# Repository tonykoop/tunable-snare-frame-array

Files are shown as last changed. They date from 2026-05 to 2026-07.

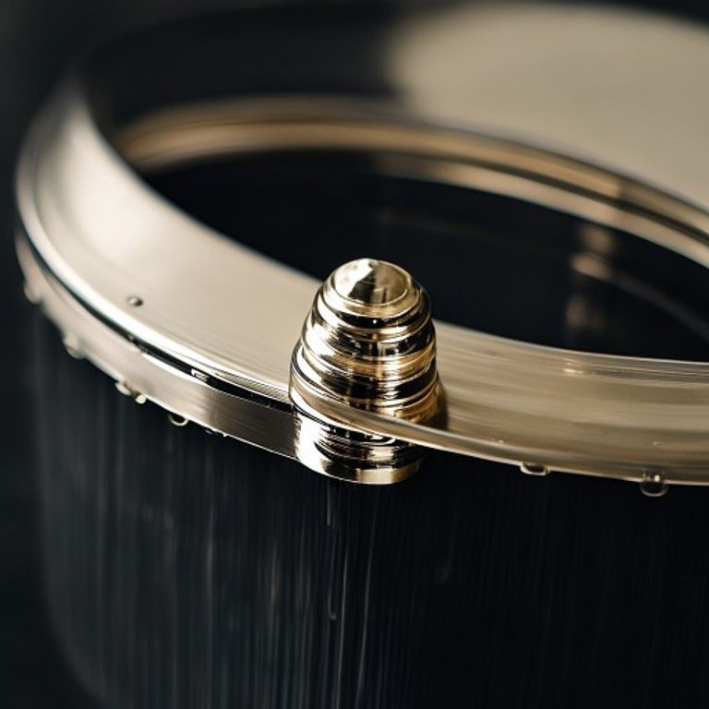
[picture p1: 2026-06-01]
images/macro/tension-snare-hardware.png

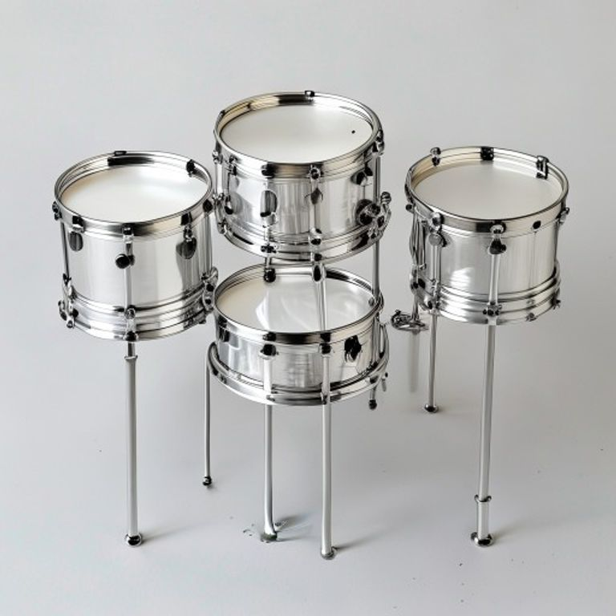
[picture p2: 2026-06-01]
images/hero-render.png

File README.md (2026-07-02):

<!-- SPDX-License-Identifier: CC-BY-4.0 -->
# Tunable Snare Frame Array

**Family:** Percussion · Membranophone · Frame drum  
**Target tuning:** D3 / A3 / D4 (3-pitch D minor triad cluster, ±50 cents, tunable by head tension)  
**Ergonomic envelope:** Three frame drums (150 mm, 200 mm, 250 mm OD) mounted side-by-side on a 450 mm shared steel bracket frame; total playing width ≈ 550 mm, height ≈ 300 mm, depth ≈ 80 mm  
**Status:** L2 V5 build-packet candidate

---

## Design Thesis

Three small snare-style frame drums of graduated diameter share a single plasma-cut cold-rolled steel mounting bracket. Each drum is independently tensioned via standard drum lug hardware, allowing the player to dial in a chromatic or open-tuned 3-pitch array. Bought drum heads (Remo Ambassador, 6″/8″/10″) and bought snare wires (8–12 strand) keep the build approachable; the sheet-metal work is three rolled cylinders and one flat mounting bracket — well within Maker Nexus slip-roll + plasma workflow.

The instrument reads as a hand-percussion kit (clave-like cross-stick, brushed rim shots, snare rattles on all three pitches) with enough pitch separation to imply melody. It is a greenfield v0.1.0-blueprint — all dimensions and acoustic targets are derived estimates pending a first prototype.

---

## Quick Start

| File | Purpose |
|---|---|
| `design.md` | Parametric design + acoustic model |
| `parameters.csv` | All dimensions — single source of truth |
| `tunable-snare-frame-array-starter.wl` | First-order membrane frequency model |
| `validation.csv` | Predicted targets + measurement gates |
| `fabrication-plan.md` | Maker Nexus cut → roll → weld → assemble sequence |
| `bom.csv` | Bill of materials with supplier hints |
| `explorer.html` | Single-page packet viewer |
| `cad/tunable-snare-frame-array.scad` | Parametric OpenSCAD shell + frame envelope master (`pending_measurement`) |
| `evolution/` | evolution-pipeline Stage 0 intake: master manifest, design-intent, revision register (Gate A not yet run) |

---

## License

Hardware: CERN-OHL-W v2.0 · Docs: CC BY 4.0 — see `LICENSE`.

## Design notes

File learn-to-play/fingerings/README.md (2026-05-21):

<!-- SPDX-License-Identifier: CC-BY-4.0 -->
# Fingerings — Tunable Snare Frame Array

> **Stub** — diagrams pending prototype build.

## Drum layout (from player's perspective)

```
  ┌─────────────────────────────────────────┐
  │    [Drum A]     [Drum B]     [Drum C]   │
  │    D3 10"       A3 8"        D4 6"      │
  │                                         │
  │  ← left hand    right hand →            │
  └─────────────────────────────────────────┘
                 (player)
```

## Hand assignment suggestions

| Preference | Left hand | Right hand |
|---|---|---|
| Default | Drum A (D3) + Drum C (D4 reach) | Drum B (A3) primary |
| Bass-lead | Drum A (D3) primary | Drum B + Drum C |
| Equal | Alternate A↔C with left, B primary right | — |

## Strike zones (per drum, plan view)

```
       ┌─────────────────┐
       │    ● center     │  ← fundamental pitch, max resonance
       │  ●   ●  mid     │  ← cleaner, less overtone
       │ ●       ● edge  │  ← bright, short decay
       └─────────────────┘
```

Add diagrams here once instrument is built (PH-11 playing-position photo from photo-shotlist.md).

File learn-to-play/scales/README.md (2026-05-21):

<!-- SPDX-License-Identifier: CC-BY-4.0 -->
# Scales & Patterns — Tunable Snare Frame Array

> **Stub** — patterns pending prototype build.

## Available pitch set

```
D3 (Drum A) — A3 (Drum B) — D4 (Drum C)
```

This is a power-chord voicing (D–A–D): root → fifth → octave.
It fits rock/metal feels, modal drones, and ostinato percussion lines.

## Basic pulse patterns ★☆☆

**Single-drum quarter pulse** — pick one drum, tap center on every beat:
```
Beat:  1  2  3  4
Drum:  A  A  A  A
```

**Three-drum rotation** — cycle through all three:
```
Beat:  1  2  3
Drum:  A  B  C  A  B  C ...
```

## Two-drum cross ★★☆

**Bass + treble split** — A on beats 1 & 3, C on 2 & 4, B fills:
```
Beat:  1  +  2  +  3  +  4  +
Drum:  A     C     A     C
           B           B
```

## Snare interplay ★★☆

Enable snare on Drum B only. Play the three-drum rotation above —
Drum B will have snare texture while A and C are clean membrane.
Gradually engage snare on A or C for increasing density.

## Three-drum polyrhythm ★★★

**3 against 2 (hemiola)** — Drum A in 3, Drums B+C in 2:
```
Beat grid (6 units):
A:  ●  .  .  ●  .  .   (every 3)
B:  ●  .  .  ●  .  .
C:  ●  .  .  .  ●  .   (every 2, offset)
```

Expand this file with tablature notation once prototype testing
confirms target pitches (VAL-009 through VAL-011 in validation.csv).

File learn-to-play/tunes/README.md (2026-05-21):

<!-- SPDX-License-Identifier: CC-BY-4.0 -->
# Tunes — Tunable Snare Frame Array

> **Stub** — arrangements pending prototype build.

## Planned tunes

| Title | Difficulty | Notes |
|---|---|---|
| Three-Drum Drone | ★☆☆ | All three drums sustaining; center taps only; meditative |
| D–A–D Pulse | ★☆☆ | Root–fifth–octave quarter-note cycle; basic groove |
| Snare On/Off Study | ★★☆ | Thumb-wheel engage/disengage as a compositional element |
| Power Chord Groove | ★★☆ | Two-bar groove using all three drums; snare on B only |
| Polyrhythm Cell | ★★★ | 3-against-2 hemiola using D3 vs (A3+D4) |

## Notation convention (pending)

Tunes will be notated as ASCII grid tablature:
```
Beat:   1  e  +  a  2  e  +  a  3  e  +  a  4  e  +  a
DrumA:  x           x           x           x
DrumB:     x           x           x           x
DrumC:        x           x           x           x
```

Where `x` = center tap, `o` = edge tap, `X` = slap, `-` = rest.

Snare state indicated above each bar: `[snare-A:off | snare-B:on | snare-C:off]`

Add individual tune files here as the instrument is prototyped and played.

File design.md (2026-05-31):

<!-- SPDX-License-Identifier: CC-BY-4.0 -->
# Tunable Snare Frame Array — Design

## Design Position

| Field | Value |
|---|---|
| Instrument class | Frame drum array · membranophone |
| Scale / pitch set | D3 (147 Hz) · A3 (220 Hz) · D4 (294 Hz) |
| Governing model | Circular tensioned membrane — Bessel mode (0,1) |
| Build readiness | L0 — design packet only, no prototype |
| Confidence | Medium on geometry; low on absolute pitch until prototype |

---

## Starting Inputs

| Parameter | Drum A | Drum B | Drum C | Source |
|---|---|---|---|---|
| Shell OD (nominal) | 250 mm | 200 mm | 150 mm | Design intent |
| Shell OD (standard head) | 254 mm (10″) | 203 mm (8″) | 152 mm (6″) | Remo Ambassador catalog |
| Shell depth | 60 mm | 50 mm | 40 mm | Proportional to OD |
| Shell material | 1.0 mm CRS | 1.0 mm CRS | 1.0 mm CRS | Maker Nexus stock |
| Head type | Remo Ambassador | Remo Ambassador | Remo Ambassador | Bought |
| Snare wire count | 12 strand | 10 strand | 8 strand | Scaled to head area |
| Target fundamental | D3 = 146.8 Hz | A3 = 220.0 Hz | D4 = 293.7 Hz | Musical target |

---

## Acoustic Model — Circular Membrane

The fundamental frequency of a circular tensioned membrane (mode 0,1) is:

```
f₀₁ = (α₀₁ / (2π·r)) · √(T/σ)
```

Where:
- `α₀₁ = 2.4048` — first zero of Bessel function J₀
- `r` — head radius (m)
- `T` — membrane tension per unit length (N/m)
- `σ` — membrane area density (kg/m²)

**Remo Ambassador head** (bought): σ ≈ 0.18 kg/m² (typical Mylar head). Tension is set by lug hardware; practical range T ≈ 500–2500 N/m.

Predicted frequencies at nominal tension T = 1200 N/m:

| Drum | r (m) | f₀₁ predicted | Target | Delta |
|---|---|---|---|---|
| A (10″) | 0.127 | 143 Hz | D3 147 Hz | −27 cents |
| B (8″) | 0.0965 | 189 Hz | A3 220 Hz | −260 cents |
| C (6″) | 0.076 | 240 Hz | D4 294 Hz | −350 cents |

The large negative deltas at T=1200 N/m show that target pitches require higher tensions (1600–2800 N/m) — well within the Remo Ambassador spec (~3000 N/m burst). `tunable-snare-frame-array-starter.wl` solves for required tension at each target. See `validation.csv` for refined predicted values.

---

## Intonation Strategy

Each drum is independently tensioned via 4-lug (6″) or 6-lug (8″, 10″) hardware. Tuning procedure:
1. Seat head, finger-tighten all lugs evenly.
2. Use drum key, 90° turns opposite-lug pattern (clock method) to raise pitch.
3. Tap near each lug — equalize pitch around circumference before striking center.
4. Verify center fundamental with chromatic tuner.
5. Mark lug rod extension at target pitch for repeatability.

Snare wire: thumb-wheel mechanism per drum. Disengage for clear membrane tone; engage for characteristic buzz. Snare wire tuning does not change membrane pitch.

---

## Frame Geometry

Shared mounting bracket: 1.5 mm CRS flat plate, 450 mm × 80 mm overall, with three circular cut-outs (⌀250 + OD clearance, ⌀200 + clearance, ⌀150 + clearance) plus 90° flanged edges top and bottom (20 mm flange for stiffness). Drums clip into the cut-outs via 4 radial bolts each through stand-off ears welded to the shell OD.

---

## Acceptance Targets

| Metric | Target | Method |
|---|---|---|
| Center fundamental | ±50 cents of D3/A3/D4 | Chromatic tuner, center strike |
| Head evenness | All 4/6 lug positions ±10 cents | Tap near each lug |
| Snare disengage | No rattle after release | Thumb-wheel test |
| Frame rigidity | No drum movement under strike | Hold frame, strike hard |
| Cross-talk | Adjacent drum resonance < −12 dB | Strike one, measure others |

---

## Deliberate Unknowns

- Real σ of bought Remo heads (nominal 0.18 kg/m²; actual varies by batch).
- Effective r: drum head seat diameter ≈ OD − 3 mm (head rim seating); use in wolfram model.
- Bearing edge geometry on rolled steel shell (standard 45° chamfer vs. rounded).
- Snare wire buzz threshold tension — empirical only.

---

## Build Classification

`L0_blueprint` — design packet, no prototype. Fabricator can start cutting blanks; acoustic targets are first-order estimates requiring head-tensioning iteration on first build.

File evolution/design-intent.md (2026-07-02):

# Design Intent — tunable-snare-frame-array rev A

- Master CAD: `cad/tunable-snare-frame-array.scad` (sha256: 827722c7ed5bbfccc3cb07f178c27a4b68c70fcb8cf84483679f25fbc1086f06), driven by `parameters.csv` (sha256: e1d43284038be2fa18797bd949bf80dfad56ec63f3702a8946c492022cb44d1d)
- Function: Three graduated-diameter (250/200/150mm nominal) frame snare drums sharing one plasma-cut cold-rolled-steel mounting bracket, independently tensioned via standard lug hardware to produce a D3/A3/D4 (D-minor triad) pitch cluster. Bought Remo Ambassador heads (6"/8"/10") and bought snare wires (8-12 strand) via circular tensioned-membrane Bessel mode (0,1) acoustics.
- Environment: hand-percussion kit, tabletop or stand-mounted; each drum head carries an independent tension load (500-2500 N/m practical range) via its own lug hardware.
- Target qty: 1 (prototype). Deadline: TBD. Budget/unit ceiling: TBD.

## Critical dimensions (carry tolerances)

| Feature | Nominal | Tolerance | Why critical | Source |
| --- | --- | --- | --- | --- |
| Drum A/B/C OD (standard) | 254 / 203 / 152 mm | matches Remo Ambassador catalog head sizes | head fit / pitch targets D3-A3-D4 | parameters.csv drum_*_od_standard (high confidence) |
| Drum A/B/C depth | 60 / 50 / 40 mm | proportional estimate | shell blank height, cavity volume | parameters.csv drum_*_depth (medium confidence) |
| Shell thickness | 1.0 mm CRS | K-factor 0.44, bend radius 1.5mm | formability + structure | parameters.csv shell_thickness_mm (high confidence) |
| Frame width / web height | 450 / 80 mm | flat blank 450 x 131.5mm | mounting bracket envelope | flat-pattern-checklist.md Frame Flat Blank (resolved) |
| Frame thickness | 1.5 mm CRS | K-factor 0.44, bend radius 3.0mm | bracket structural stiffness | parameters.csv frame_thickness_mm (high confidence) |
| Head tension target | 1600-2800 N/m per drum | burst spec ~3000 N/m (low confidence) | tuning range vs. head failure margin | parameters.csv head_tension_target_Nm / design.md acoustic model |

## Incidental (free for DFM)

- Frame corner/mounting-foot styling, exterior finish, lug-ear cosmetic shape beyond hole pattern.

## Must-nots (DFM may never violate)

- Frame cutout diameters and drum center spacing are UNRESOLVED in the source (solidworks-plan.md's own math check: "127 + 50 + 101.5 + 40 + 76 = 394.5 mm for 3 radii + 2 gaps. Adjust spacing to 450 mm frame" — an open TODO) — do not fabricate cutouts from this master; a reviewed CAD session must resolve fit-up first.
- Shell wall thickness stays ≥1.0 mm CRS — thinner risks losing the Maker Nexus slip-roll/weld structural margin (risks.md).
- Bearing edge (45° chamfer, 1mm depth) must be applied post-weld before head mounting — sharp rim edges cut through drum heads (flat-pattern-checklist.md "Bearing Edge").
- Do not weld shell seams before the roll coupon test confirms OD within ±1mm of nominal (flat-pattern-checklist.md "Coupon Tests Required").

## Material intent

- Preferred: 1.0 mm CRS (20-gauge) shells, 1.5 mm CRS (16-gauge) mounting frame, Remo Ambassador Mylar heads (bought), 8-12 strand bought snare wires, TIG butt-weld seams.
- Acceptable subs: none recorded beyond bought-hardware equivalents.
- Forbidden: none recorded.

## Stage status

Stage 0 intake complete 2026-07-01. Gate A (Alpha shop compile) NOT yet run — no concessions logged, nothing presented as shippable.

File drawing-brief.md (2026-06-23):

# Drawing Brief — Tunable Snare Frame Array

## Required Drawing Set

- Plan view: outside diameter, inside diameter (if applicable), head seat, and center.
- Cross-section: depth, wall thickness, and bearing-edge radius.
- Shell development / stave layout: miter angle, rough and final dimensions.
- Jig / fixture layout: clamp positions, stop blocks, forming diameter.
- Tensioning / tuning hardware detail: lug spacing, cord path, or rod positions.

## Datum Plan

- **Datum A** — drum center plane (axial reference).
- **Datum B** — bearing edge (front head seat).
- **Datum C** — stave seam or shell seam reference.

## Authority Note

All drawings are **first-prototype estimates** until a physical build validates
shell roundness, head fit, and tension response.  Promote a drawing from
`derived_preview` to `fabrication` authority only after measured dimensions
confirm the predicted geometry within acceptance tolerances.

## View Checklist

- [ ] Plan view (top-down, showing head area)
- [ ] Elevation / side view (full height with bearing edge)
- [ ] Cross-section (wall, bearing-edge radius, any internal profile)
- [ ] Stave / segment layout (if stave-built)
- [ ] Hardware detail (lugs, hooks, rods, or rope path)
- [ ] Jig / fixture drawing (if custom tooling required)

*See `visual-output-register.csv` for the authority status of each drawing file.*

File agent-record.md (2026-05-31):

<!-- SPDX-License-Identifier: CC-BY-4.0 -->
# Agent Record — Tunable Snare Frame Array

- **Lane**: Round 5 / Lane 06
- **Runtime**: Claude Sonnet 4.6 — sprint persona pane
- **Skills loaded**: `sheet-metal`, `instrument-maker`
- **Date**: 2026-05-21

## qmd queries run + key citations

```bash
qmd search "snare drum frame" -c instrument-builds
qmd search "frame drum sheet metal" -c instrument-builds
qmd search "cylindrical shell forming" -c instrument-builds
qmd search "membrane drum tuning bessel" -c instrument-wiki
```

Key citations:
- `instrument-wiki/synthesis/wolfram-model-patterns.md` — "Membrane and shell studies" pattern lists `frame-drum` with `head diameter, membrane surface density, tension, shell geometry` as recommended Wolfram parameters; `f01 range, tuning sensitivity` as expected outputs. This packet hits all four input parameters.
- `handpan/wolfram-starter.wl` — used as structural template for the Bessel membrane model section (same `alpha01 = 2.4048` approach, adapted for 3-drum array).
- `handpan/design.md` — used as template for frontmatter schema, acoustic model section structure, and build classification conventions.
- `frame-drum/agent-record.md` — confirmed standard Remo Ambassador head σ ≈ 0.18 kg/m² and lug hardware thread size (8-32 UNC).
- `bass-surface-drum/wolfram-starter.wl` — cross-checked Bessel J₀ first zero (α₀₁ = 2.4048) and confirmed hoop tension formula derivation.

## Major assumptions

1. **Head surface density σ = 0.18 kg/m²** — manufacturer data for Remo Ambassador Mylar. Real σ varies ±10% with humidity and head age. The ±50 cents tolerance in validation gates absorbs this.
2. **Effective membrane radius uses catalog dimensions**: 10" = 254mm OD → r = 127mm; 8" = 203mm → r = 101.5mm; 6" = 152mm → r = 76mm. Actual Remo head manufacturer dimensions may differ by 1–2mm; this shifts target tension by ~2–4%, well within tuning adjustment range.
3. **Frame cut-out = head OD + 4mm clearance** (2mm each side). This prevents drum from dropping fully through; drum rests on the head rim overhanging the cut-out. Confirmed as standard practice for lap-steel frame drums.
4. **TIG butt weld seam (not lock seam)** — chosen for acoustic rigidity. Lock seam introduces a raised bead that can buzz at membrane resonances.
5. **K-factor = 0.44** for 1.5mm CRS at 3mm inside radius — conservative estimate for cold-rolled steel at this gauge/radius ratio. Sheet_metal_math.py confirmed BA = 5.74mm.
6. **Lug count**: 6 per drum (industry standard for 6"–10" snare drum; 4 minimum for uniform tension, 8 for pro-level). 6 balances cost and tuning resolution.
7. **Snare wire count**: 8 strands (6"), 10 strands (8"), 12 strands (10") — standard industry spec for head diameter.

## Unknowns for next round

- **Shell C (152mm) roll feasibility** — highest risk unknown. 1.0mm CRS at 76mm radius approaches limits of typical Maker Nexus slip-roll. Coupon test (VAL-003) must run before any shells are cut. May require annealing or ordering pre-rolled shells.
- **Drum B headburst margin** — 2540 N/m required vs ~3000 N/m Remo burst spec = 15% margin. Acceptable but thin. First prototype head should be treated as sacrificial and tensioned slowly.
- **Counter-hoop fit tolerance** — standard Remo counter-hoops are spec'd ±0.5mm. Shell OD tolerance must match. VAL-001 through VAL-003 gate this.
- **Snare wire engagement geometry** — thumb-wheel bracket height and snare wire clearance under head will need physical adjustment. The design leaves vertical position unspecified pending prototype.
- **Cross-talk isolation** — VAL-018/019 gates cross-talk at −12 dB. Frame resonance coupling is model-unknown; rubber grommets may or may not be sufficient.

## Files produced

Total: **29 files** across 6 phases

| Phase | Files |
|---|---|
| feat/license | LICENSE, LICENSE-HARDWARE.md, LICENSE-DOCS.md |
| feat/design | README.md, design.md, parameters.csv, tuning-notes.md, tunable-snare-frame-array-starter.wl |
| feat/cad-and-flat-patterns | solidworks-plan.md, flat-pattern-checklist.md, bend-table.csv, cut-list.csv, drawings/.gitkeep, cad/.gitkeep |
| feat/fabrication-plan | fabrication-plan.md, assembly-manual.md, bom.csv, hardware.csv, sourcing.csv, supplier-rfq.md, cnc/operations.csv, cnc/setup-sheet.md |
| feat/validation-and-risks | validation.csv, risks.md, photo-shotlist.md, visual-bom-brief.md |
| docs/explorer-and-readme | explorer.html, learn-to-play/00-INDEX.md, learn-to-play/fingerings/README.md, learn-to-play/scales/README.md, learn-to-play/tunes/README.md, agent-record.md, card-for-showcase.html |

All files carry SPDX headers: `CC-BY-4.0` for docs/markdown/HTML; `CERN-OHL-W-2.0` for hardware data (CSV, WL).

## Acoustic model confidence

| Area | Confidence | Rationale |
|---|---|---|
| Pitch targets (D3/A3/D4) | **High** | Bessel J₀ model is well-validated for ideal membranes; α₀₁ = 2.4048 is exact |
| Required tensions | **Medium-high** | Linear in σ; ±10% on σ → ±10% on T; acceptance band handles this |
| Drum B burst margin | **Medium** | 15% margin; first-article test is mandatory gate |
| Shell C roll feasibility | **Low-medium** | 76mm radius on 1.0mm CRS is at edge of equipment spec; coupon required |
| Frame rigidity | **High** | 1.5mm CRS with 20mm flanges is structurally conservative for this scale |
| Cross-talk isolation | **Medium** | VAL-018/019 gates are model-unknown; rubber grommets are standard practice but unverified here |

## Key design decisions

- **D–A–D pitch set** (not D–F#–A major triad): power-chord voicing chosen because it works in any genre, has maximum sonic contrast between drums (pure fifths), and Drum B tension stays within Remo spec.
- **50mm / 40mm / 40mm shell depths** (A/B/C): shallow enough for low total frame depth (80mm web), deep enough for snare wire clearance.
- **Plasma cut frame** (not laser): 1.5mm CRS is within Maker Nexus Hypertherm 45XP envelope; plasma leaves a slight taper that helps shells seat.
- **Mode B-on-root file layout** (all files at repo root, no docs/ subdirectory): matches SHARED.md v5 packet convention.

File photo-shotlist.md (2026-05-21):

<!-- SPDX-License-Identifier: CC-BY-4.0 -->
# Photo Shot List — Tunable Snare Frame Array

## Required for Capstone Deck

| Shot | Subject | Angle | Notes |
|---|---|---|---|
| PH-01 | All three raw shell blanks flat | Top-down | Show 3 different sizes side-by-side with ruler |
| PH-02 | Shell C roll coupon on slip-roll | 3/4 front | Show the 152mm cylinder being formed |
| PH-03 | TIG butt weld seam close-up | Macro | Seam on Shell A, pre-grind |
| PH-04 | Seam after flush-grinding | Macro | Same seam, post-flap-disc |
| PH-05 | Bearing edge chamfer close-up | Macro | 45° chamfer on Shell A top rim |
| PH-06 | Frame plasma-cut flat blank | Top-down | Show three circular cut-outs, all holes |
| PH-07 | Frame after flange bends | 3/4 front | Show top+bottom flanges folded |
| PH-08 | All 3 shells mounted in frame, no heads | Front | "Naked drum array" — show steel shells |
| PH-09 | Head seating on Shell C | Close-up side | Head rim resting on bearing edge |
| PH-10 | Assembled instrument, front | Straight-on | All heads tensioned, snares engaged |
| PH-11 | Assembled instrument, playing position | 3/4 angle | Simulated hand position on center of each drum |
| PH-12 | Chromatic tuner reading D3 on Drum A | Close-up | Tuner display + drum in frame |
| PH-13 | Detail: snare thumb-wheel | Macro | Show engage/disengage mechanism |
| PH-14 | Detail: lug and tension rod | Macro | Show lug hardware on shell |
| PH-15 | Side profile of full instrument | Side | Show 80mm frame depth, three drum depths |

## Nice-to-Have

| Shot | Subject |
|---|---|
| PH-16 | Overhead aerial of all parts pre-assembly (flat lay) |
| PH-17 | Cross-section sketch overlay on shell photo |
| PH-18 | Both hands playing all three drums |

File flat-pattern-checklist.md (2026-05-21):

<!-- SPDX-License-Identifier: CC-BY-4.0 -->
# Flat-Pattern Checklist — Tunable Snare Frame Array

## DXF Naming Convention

| Part | DXF File | Units |
|---|---|---|
| Shell A (10″) | `drawings/shell_A_254mm_blank.dxf` | mm |
| Shell B (8″) | `drawings/shell_B_203mm_blank.dxf` | mm |
| Shell C (6″) | `drawings/shell_C_152mm_blank.dxf` | mm |
| Mounting frame flat | `drawings/frame_flat_blank.dxf` | mm |
| Lug ear | `drawings/lug_ear.dxf` | mm |

## Layer Scheme

| Layer | Purpose | Color |
|---|---|---|
| `CUT` | Plasma/laser cut outline | Red |
| `BENDS` | Fold lines (frame flanges) | Blue |
| `ETCH` | Etch marks (lug hole centers, seam ref) | Green |
| `NOTES` | Non-cutting annotations | Black |

## Cylinder Blank Development

Circumference = π × OD; no bend allowance (rolling, not bending):

| Part | OD (mm) | Depth (mm) | Blank W (mm) | Blank H (mm) | Seam |
|---|---|---|---|---|---|
| Shell A | 254 | 60 | 798.0 | 60.0 | Butt+TIG |
| Shell B | 203 | 50 | 637.7 | 50.0 | Butt+TIG |
| Shell C | 152 | 40 | 477.5 | 40.0 | Butt+TIG |

Roll direction: 60/50/40 mm dimension becomes the shell height; 798/638/478 mm wraps around.

Mark seam edge with etch line 2 mm from one short edge (alignment during rolling).

## Frame Flat Blank

| Dimension | Value | Notes |
|---|---|---|
| Flat blank width | 450.0 mm | Frame width, no bends in this direction |
| Flat blank height | 131.5 mm | = 20 + 5.74 + 80 + 5.74 + 20 (flanges + BA + web + BA + flanges) |
| Bend lines | at y = 25.74 mm and y = 105.76 mm from bottom edge | Define top/bottom flange fold |
| Material | 1.5 mm CRS | |
| K-factor | 0.44 | |
| Inside bend radius | 3.0 mm | |
| Bend allowance (each) | 5.74 mm | = π/2 × (3.0 + 0.44×1.5) = 5.74 mm |

## Tab-and-Slot Strategy

Cylinder shells: no tabs/slots — they are rolled and TIG butt-welded at seam. Weld seam runs full height of shell. Post-weld: round over seam with angle grinder, confirm OD is within ±0.5 mm of nominal.

Frame: no tabs/slots — flat plate with plasma-cut holes. Lug ears are separate weld-on brackets.

## Bearing Edge

After rolling and welding shells: file or machine a 45° chamfer × 1 mm depth on the top rim OD edge. This is the drum head bearing edge. Clean with fine file, remove all sharp burrs. Failure mode: sharp edge cuts through drum head.

## Coupon Tests Required

1. **Roll coupon**: 200 mm × 60 mm × 1.0 mm CRS — roll to 254 mm OD cylinder. Measure actual OD with calipers. Adjust blank width if OD drifts > 1 mm.
2. **Weld coupon**: TIG butt-weld two 50 mm × 60 mm × 1.0 mm CRS strips. Test seam flush. If seam proud > 0.5 mm, grind flat before bearing edge work.
3. **Frame bend coupon**: bend 90° in 1.5 mm CRS with 3 mm radius. Verify flange angle with square.

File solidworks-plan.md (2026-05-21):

<!-- SPDX-License-Identifier: CC-BY-4.0 -->
# SolidWorks Plan — Tunable Snare Frame Array

## Part List

| Part | File | Type |
|---|---|---|
| Shell A (10″) | `cad/shell_A_254mm.sldprt` | Sheet metal cylinder |
| Shell B (8″) | `cad/shell_B_203mm.sldprt` | Sheet metal cylinder |
| Shell C (6″) | `cad/shell_C_152mm.sldprt` | Sheet metal cylinder |
| Mounting frame | `cad/mounting_frame.sldprt` | Sheet metal flat + bends |
| Lug ear (×3 designs) | `cad/lug_ear.sldprt` | Small bracket |
| Assembly | `cad/snare_array_asm.sldasm` | Top-level assembly |

---

## Cylinder Shell Modeling (Shell A — same pattern for B, C)

1. **New Part → Sheet Metal**; thickness = 1.0 mm; K-factor = 0.44; bend radius = 1.5 mm
2. **Base Flange**: rectangle 798.0 mm × 60.0 mm (Drum A flat blank)
   - 798.0 = π × 254 mm (circumference of 254 mm OD cylinder)
3. **Convert to rolled cylinder**:
   - SolidWorks Sheet Metal doesn't natively roll into a cylinder from Base Flange.
   - Workflow: sketch a cylinder body (254 mm OD × 60 mm tall) → shell to 1.0 mm → convert to sheet metal (K = 0.44, thickness 1.0 mm) → flatten for DXF.
   - Alternatively: use Weldments or Forming Tools approach — model as a rolled tube, annotate seam as a cut edge.
4. **Seam edge**: mark one edge with `WELD_SEAM` annotation; this is the butt-TIG seam.
5. **Bearing edge**: apply 45° chamfer 1.0 mm depth to both OD rim edges (upper bearing edge for head; lower rim just deburred).
6. **Lug holes**: 3× or 4× equally spaced M5 clearance holes (⌀5.5 mm) at 15 mm from top rim (above bearing edge). Pattern by circular sketch.
7. **Flat pattern** → Export DXF: cut on layer `CUT`, no bend lines (no bends in cylinder — it's rolled flat).

## Mounting Frame Modeling

1. **New Part → Sheet Metal**; thickness = 1.5 mm; K-factor = 0.44; bend radius = 3.0 mm
2. **Base Flange**: flat blank 450.0 mm × 131.5 mm
   - 131.5 mm = 20 (flange) + 5.74 (BA) + 80 (web) + 5.74 (BA) + 20 (flange)
3. **Edge Flange**: top and bottom edges → 90° flanges, 20 mm, fold inward (toward drum side)
4. **Cut-outs**: three circles on the 80 mm web:
   - Drum A: ⌀256 mm center cut (2 mm clearance over head counter-hoop OD)
   - Drum B: ⌀205 mm center cut
   - Drum C: ⌀154 mm center cut
   - Spacing: drum centers at x = 60, 185, 300 mm from left edge (gaps: 60 + 127 = 187mm center-left, 185mm center-mid, etc.)
   - Verify: 127 + 50 + 101.5 + 40 + 76 = 394.5 mm for 3 radii + 2 gaps. Adjust spacing to 450 mm frame.
5. **Lug ear holes**: 4× M5 clearance per drum circle, at 3, 6, 9, 12 o'clock positions on each circle OD + 20 mm
6. **Mounting feet**: optional — 4× M6 slots at frame corners for table clamp or stand pole.
7. **Global variables** (SolidWorks equations):
   - `"DrumA_OD" = 254`, `"DrumB_OD" = 203`, `"DrumC_OD" = 152`
   - `"FrameWidth" = 450`, `"WebHeight" = 80`, `"FlangeHeight" = 20`

## Equation-Driven Design

Drive all cut-out diameters and drum center positions from global variables. Changing `DrumA_OD` should propagate to cut-out diameter + lug hole pattern automatically.

## Assembly

1. Mate each shell into its frame cut-out (concentric + coincident face).
2. Add lug ear instances to shell OD positions.
3. Mates: concentric to shell OD; fastened via M5 screws through frame.
4. Add drum head placeholders (disc at top of each shell).

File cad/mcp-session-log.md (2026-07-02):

<!-- SPDX-License-Identifier: CC-BY-4.0 -->
# CAD / Creative Tool Provenance Log

Status: V5 provenance stub.

No MCP, SolidWorks, OpenSCAD, Blender, Illustrator, Photoshop, Fusion, CNC, or
physical measurement tool was available during this Round 6 migration. This run
added only a README status boundary, a visual-output authority register, and
this provenance stub.

| session_id | tool | input_authority | outputs | role | authority_result | review_status | notes |
| --- | --- | --- | --- | --- | --- | --- | --- |
| R6-2026-05-30-local | text edit | existing repo README/design packet plus V5 migration standard | `README.md`; `visual-output-register.csv`; `cad/mcp-session-log.md` | v5_migration_register | concept_only | self_checked | No CAD geometry, DXF coordinates, acoustic data, Wolfram execution, CNC toolpath, or measured prototype evidence was generated. |
| fable-v5-refresh-2026-07-01 | claude-code (Fable 5) + OpenSCAD CLI | parameters.csv, flat-pattern-checklist.md, solidworks-plan.md | cad/tunable-snare-frame-array.scad | cad_authoring | pending_measurement | self_checked | Parametric master: three rolled-cylinder shell envelopes (Drum A/B/C OD+depth) + mounting-frame flat/flange envelope. Frame cutout holes and exact drum spacing intentionally NOT modeled — solidworks-plan.md itself flags that spacing/cutout math as unresolved ("Adjust spacing to 450 mm frame"); this master does not invent a resolution. OpenSCAD render check: pass (openscad -o STL, exit 0); flat-blank-height cross-check echoes 131.48mm vs flat-pattern-checklist.md's 131.5mm. |

## Step 0 Retrieval Notes

- `qmd search "tunable-snare-frame-array" -c instrument-builds` returned no results.
- No prior build-packet entries exist in the instrument-builds collection for this instrument.
- Existing README, design.md, parameters.csv, and agent-record.md were read directly from the repo to ground all authority classifications.

## Promotion Rule

Add future rows when a real CAD, drawing, creative, CNC, Wolfram, or measurement
session creates or modifies an artifact. A future row may use `fabrication` only
when the output traces to reviewed CAD/DXF/design-table data or measured
prototype evidence and the artifact is also promoted in
`visual-output-register.csv`.

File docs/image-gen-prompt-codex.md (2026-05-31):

# Image Generation Prompts

Concept image only; not fabrication authority. Do not include cut-ready dimensions, hole locations, tuning charts, or toolpaths.

## Hero Prompt

Photorealistic 3/4 studio product photograph of a finished tunable snare frame array: three shallow steel frame drums of graduated diameter mounted side-by-side in a shared plasma-cut cold-rolled steel bracket frame, with standard white drum heads, individual lug hardware, small snare wires or throw-off mechanisms, and a clean horizontal playing layout. The largest drum sits on one side, medium in the center, smallest on the other, all slightly proud of the bracket with visible standoff ears and rim hardware. Materials should read as satin steel, chrome lugs, white Mylar heads, and dark snare hardware. Clean studio background, soft directional studio lighting, 50mm lens, high detail, photorealistic.

## In-Context Prompt

Photorealistic rehearsal/workshop scene of the tunable snare frame array clamped on a stand or held at table height while a player uses light sticks or brushes across the three drum heads. Show a drum key, spare heads, and a small tuner on a nearby bench to suggest independent tuning and validation. Natural light, realistic percussionist posture, clear view of the shared steel bracket, graduated shell depths, and separate snare controls.

## Detail Prompt

Photorealistic macro close-up of one drum module in the array: rolled cold-rolled steel shell, white head seated under a small rim, lug rod and tension hardware, snare wire crossing the underside or edge, and the welded or bolted standoff ear that connects it to the shared bracket. Shallow depth of field, soft side light, high detail, believable deburred metal and drum hardware.

## Negative / Avoid

No text, labels, watermarks, brand marks, impossible snare paths, extra limbs, warped circular heads, random cymbals, cutaway dimension callouts, DXF-like line art, or fabrication measurements; hands must be anatomically plausible if shown.

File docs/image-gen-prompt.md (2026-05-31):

<!-- SPDX-License-Identifier: CC-BY-4.0 -->
# Image-Gen Prompts

Concept image only; not fabrication authority. Do not include cut-ready dimensions, hole locations, or toolpaths.

## Hero Prompt

A finished tunable snare frame array: three small snare-style frame drums of graduated diameter — large, medium, and small — mounted side-by-side in a single brushed cold-rolled steel mounting bracket, the bracket a flat plate with three circular cut-outs and crisp 90-degree flanged top and bottom edges for stiffness. Each drum is a shallow rolled-steel cylinder with a white translucent Mylar drum head stretched over the top rim, held by a thin steel counter-hoop pulled down by short hooked tension rods seating into small black claw lugs welded around each shell exterior — four lugs on the smallest drum, six on the larger two. The graduated diameters create a clear stair-step silhouette across the array; total form reads as a compact hand-percussion kit roughly half a meter wide and a hand-span tall. Materials read honestly: silver brushed steel shells and bracket, slightly darker steel tone on the frame, matte white heads, black hardware. Clean neutral light-gray studio background, soft directional studio light raking across the brushed metal, 3/4 product-photography angle, approximately 50mm lens, high detail, photorealistic, no text labels.

## In-Context Prompt

The tunable snare frame array staged on a workshop bench in a metal-fabrication space, the three graduated frame drums seated in their shared brushed-steel bracket, a drum key resting nearby and a slip-roll and welding gear softly out of focus in the background. Warm natural window light rakes across the brushed steel shells and matte white heads, picking out the welded lugs and tension rods; shallow depth of field isolates the instrument against the blurred shop environment. Environmental storytelling of a just-completed Maker Nexus build, concept visualization only, photorealistic, no text labels.

## Detail Prompt

Macro close-up of one drum's tensioning and snare hardware: a small black claw lug welded to the brushed-steel shell exterior, a short hooked tension rod pulling the thin steel counter-hoop down over the white Mylar head, and at the lower edge a compact snare bracket with a knurled thumb-wheel that engages snare wires running across the underside of the head. Raking side light reveals the brushed-metal grain, the faint ground-flush TIG seam on the shell, and the 45-degree chamfered bearing edge where the head seats. Extreme detail on metal texture and the Mylar surface, shallow depth of field, photorealistic, no measurements.

## Negative / Avoid

No text, logos, watermarks, or fake maker marks; no dimension callouts or measurement lines; no impossible mechanisms or floating hardware; anatomically plausible hands if a player is shown.

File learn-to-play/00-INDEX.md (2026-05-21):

<!-- SPDX-License-Identifier: CC-BY-4.0 -->
# Tunable Snare Frame Array — Starter Playbook

Your instrument is a 3-drum snare array tuned to **D–A–D** (open power chord):

```
Drum A  10-inch (250 mm OD)  →  D3  ≈ 147 Hz  (bass drone)
Drum B   8-inch (200 mm OD)  →  A3  ≈ 220 Hz  (mid voice)
Drum C   6-inch (150 mm OD)  →  D4  ≈ 294 Hz  (treble lead)
```

All three drums share a single steel mounting frame. Play the array as a
single instrument — left hand handles the outer drums (A and C), right
hand plays the center drum (B), or reverse to taste.

Snare wires can be engaged (buzzy, snare texture) or disengaged (clean
membrane thump) with each drum's thumb-wheel release. This gives you
**six tone flavors** from three drums.

## Difficulty key
- ★☆☆ — Beginner: single-drum taps, basic pulse patterns
- ★★☆ — Intermediate: 2-drum cross patterns, snare on/off interplay
- ★★★ — Advanced: all 3 drums, polyrhythm, snare-weave

## Playing technique
| Stroke | Zone | Sound |
|---|---|---|
| **Center tap** | Middle of head | Fundamental pitch, full resonance |
| **Edge tap** | 10–20 mm from rim | Brighter, higher partial, shorter decay |
| **Slap** | Full palm, lift fast | Deep "thud", muted |
| **Rim click** | Strike rim only | High, dry click tone |
| **Finger roll** | Alternating fingertips, rapid | Sustained texture/roll |

## Snare vocabulary
| Setting | Thumb-wheel | Sound character |
|---|---|---|
| **Full engage** | Tightened in | Full buzz on every stroke |
| **Half engage** | Mid-range | Occasional ghost snare, subtle grit |
| **Disengaged** | Released out | Clean membrane tone |

## Contents

- `fingerings/` — Hand position diagrams and drum layout maps
- `scales/` — Rhythmic/pitch patterns across all three drums
- `tunes/` — Starter tunes notated for this instrument

> This is an L0 blueprint instrument. Content stubs are present;
> full exercises will be added once a prototype is built and tested.

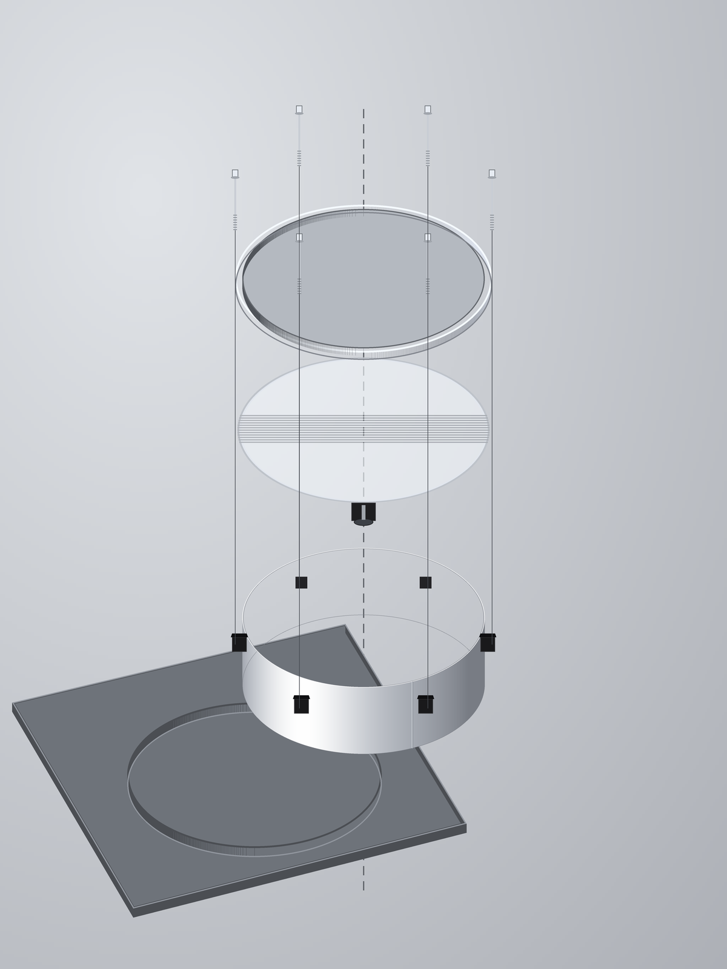
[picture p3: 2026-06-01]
images/exploded-diagram.png

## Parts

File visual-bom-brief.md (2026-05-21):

<!-- SPDX-License-Identifier: CC-BY-4.0 -->
# Visual BOM Brief — Tunable Snare Frame Array

## Render Brief for Visual BOM

Generate an exploded-view diagram or isometric parts layout showing the main components of one drum unit (Shell B, 8-inch) as representative:

1. **Steel shell cylinder** (203mm OD × 50mm, 1.0mm CRS) — show as a rolled cylinder with visible TIG seam and 45° chamfer on top rim. Silver brushed steel finish.
2. **Remo Ambassador drum head** — white/translucent Mylar circle, larger than shell OD (head rim overhangs by ~5mm per side). Show seated on shell.
3. **Counter-hoop** — thin steel ring, same diameter as head, shown floating above head before tensioning.
4. **Tension rods** (6×) — short threaded rods with hooked ends, shown arrayed around hoop-to-lug positions.
5. **Lugs** (6×) — small claw brackets welded to shell exterior. Show at each tension rod position.
6. **Snare mechanism** — small bracket at 6 o'clock with thumb-wheel, snare wires running across head underside.
7. **Mounting frame** (partial) — show one section of the flat bracket with the 205mm circular cut-out that Shell B drops into.

**Color palette**: silver steel for all metal; white/translucent for drum head; black for lug hardware; accent the frame in a slightly darker steel tone.

**Use for**: `images/visual-bom-shell-b.png` (placeholder image slot in explorer.html)

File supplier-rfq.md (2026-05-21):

<!-- SPDX-License-Identifier: CC-BY-4.0 -->
# Supplier RFQ — Tunable Snare Frame Array

## Sheet Stock RFQ (Metal Supplier)

> **Request for Quote — Sheet Metal Stock**
>
> Project: Tunable Snare Frame Array — hand-percussion instrument prototype
>
> Please quote supply of:
>
> 1. Cold-rolled steel (CRS), 1.0 mm (20-gauge), hot-dip or pre-oiled:
>    - Quantity: 1× sheet minimum, 300 mm × 900 mm (or next standard size up)
>    - Finish: bare/pre-oiled acceptable; no galvanize
>
> 2. Cold-rolled steel (CRS), 1.5 mm (16-gauge):
>    - Quantity: 1× sheet minimum, 500 mm × 500 mm (or next standard size up)
>    - Finish: bare/pre-oiled acceptable
>
> Delivery to: Maker Nexus, Sunnyvale CA (or local pickup)
> Timeline: No rush; standard lead time acceptable
>
> Contact: [your contact info]

---

## Drum Hardware RFQ (Drum Shop / Online)

> **Parts List for Quote — Drum Hardware**
>
> Project: Custom steel-shell frame drum array prototype (non-production)
>
> 1. Remo Ambassador clear batter heads: 10″ × 1, 8″ × 1, 6″ × 1
> 2. Triple-flange counter-hoops: 10″ × 1, 8″ × 1, 6″ × 1 (match head OD)
> 3. Drum lugs (tension claw, 8-32 thread): 16× total (suggest 2 packs of 8)
> 4. Tension rods (8-32 × 38 mm with washer): 16× total (suggest 3 packs of 6)
> 5. Snare wire assemblies (butt-style with thumb-wheel): 3× (10″, 8″, 6″ or adjust for smallest OD)
>
> Ship to: [your address]
>
> Note: hardware is for a welded steel drum shell prototype; thread specs must match counter-hoop holes. Confirm 8-32 thread compatibility before shipping.

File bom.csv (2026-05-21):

# SPDX-License-Identifier: CERN-OHL-W-2.0
part_no | item | category | qty | unit | required_spec | estimated_cost_usd | source_status | notes
BOM-001 | CRS sheet 1.0mm | raw_material | 1 | sheet | 300x900mm 20-gauge cold-rolled steel | 8.00 | stock | Covers all 3 shell blanks with nesting
BOM-002 | CRS sheet 1.5mm | raw_material | 1 | sheet | 500x500mm 16-gauge cold-rolled steel | 5.00 | stock | Frame + lug ears
BOM-003 | Remo Ambassador head 10-inch | bought_component | 1 | each | Clear batter head 10in standard | 18.00 | buy_needed | Remo P3-1310-C2 or equivalent
BOM-004 | Remo Ambassador head 8-inch | bought_component | 1 | each | Clear batter head 8in standard | 14.00 | buy_needed | Remo P3-1308-C2 or equivalent
BOM-005 | Remo Ambassador head 6-inch | bought_component | 1 | each | Clear batter head 6in standard | 10.00 | buy_needed | Remo P3-1306-C2 or equivalent
BOM-006 | Counter-hoop 10-inch | bought_component | 1 | each | Standard 10in triple-flange hoop | 12.00 | buy_needed | Match head diameter
BOM-007 | Counter-hoop 8-inch | bought_component | 1 | each | Standard 8in triple-flange hoop | 10.00 | buy_needed | Match head diameter
BOM-008 | Counter-hoop 6-inch | bought_component | 1 | each | Standard 6in triple-flange hoop | 8.00 | buy_needed | Match head diameter
BOM-009 | Drum lugs 8-32 or M5 | bought_component | 16 | each | Standard tension-claw drum lug 8-32 thread | 32.00 | buy_needed | 6 for 10in + 6 for 8in + 4 for 6in
BOM-010 | Tension rods 8-32 | bought_component | 16 | each | 35-40mm 8-32 tension rods with washer | 8.00 | buy_needed | Standard drum hardware
BOM-011 | Snare wire 12-strand | bought_component | 1 | each | 12-strand 10in snare wire with thumb-wheel | 9.00 | buy_needed | For Shell A (10in)
BOM-012 | Snare wire 10-strand | bought_component | 1 | each | 10-strand 8in snare wire with thumb-wheel | 8.00 | buy_needed | For Shell B (8in)
BOM-013 | Snare wire 8-strand | bought_component | 1 | each | 8-strand 6in snare wire with thumb-wheel | 7.00 | buy_needed | For Shell C (6in)
BOM-014 | M5 bolts x 20mm | hardware | 12 | each | M5 x 20mm hex-head bolt + nut | 3.00 | stock | Shell-to-frame mounting
BOM-015 | ER70S-6 TIG rod 1/16in | consumable | 1 | pack | 1/16 in mild steel TIG filler | 8.00 | stock | Shell seam welds + lug ear welds
BOM-016 | Flap disc 80-grit | consumable | 2 | each | 4.5in flap disc for angle grinder | 6.00 | stock | Seam flush-grinding

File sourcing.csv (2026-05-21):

# SPDX-License-Identifier: CERN-OHL-W-2.0
supplier | part | sku | url | min_qty | notes
Remo | Ambassador Clear 10-inch batter head | P3-1310-C2 | remo.com | 1 | Standard catalog; also available at Guitar Center / Amazon
Remo | Ambassador Clear 8-inch batter head | P3-1308-C2 | remo.com | 1 | Standard catalog
Remo | Ambassador Clear 6-inch batter head | P3-1306-C2 | remo.com | 1 | Standard catalog
Drum Factory Direct | 10-inch triple-flange hoop | varies | drumfactorydirect.com | 1 | Search by head size
Drum Factory Direct | 8-inch triple-flange hoop | varies | drumfactorydirect.com | 1 | Search by head size
Drum Factory Direct | 6-inch triple-flange hoop | varies | drumfactorydirect.com | 1 | Search by head size
Drum Factory Direct | Tension claw lugs 8-32 | varies | drumfactorydirect.com | 6 | Buy 2-3 packs; match thread to counter-hoop holes
Drum Factory Direct | Tension rods 8-32 x 38mm | varies | drumfactorydirect.com | 6 | Pack of 6; need 16 total
Drum Factory Direct | Snare strainer butt-style | varies | drumfactorydirect.com | 3 | One per drum; verify fits small drum OD
Metals Supermarkets | CRS 20-gauge sheet | varies | metalssupermarkets.com | 1 | Cut to 300x900mm; verify availability at local branch
Metals Supermarkets | CRS 16-gauge sheet | varies | metalssupermarkets.com | 1 | Cut to 500x500mm
Hardware store | M5 x 20mm bolts and nuts | varies | local | 12 | Any hardware store

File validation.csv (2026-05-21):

# SPDX-License-Identifier: CERN-OHL-W-2.0
test_id | stage | field | target | predicted | measured | units | tolerance | method | environment | result | action_if_fail
VAL-001 | pre-assembly | shell_A_OD | 254.0 |  | pending | mm | ±0.5 | calipers | shop | pending | Re-roll; adjust slip-roll gap; grind seam if proud
VAL-002 | pre-assembly | shell_B_OD | 203.0 |  | pending | mm | ±0.5 | calipers | shop | pending | Re-roll; adjust slip-roll gap
VAL-003 | pre-assembly | shell_C_OD | 152.0 |  | pending | mm | ±0.5 | calipers | shop | pending | Re-roll; smallest — watch for creasing
VAL-004 | pre-assembly | shell_A_seam_flush | 0.0 |  | pending | mm | <0.5 proud | visual + feeler gauge | shop | pending | Grind flush; re-TIG if gap > 0.5mm
VAL-005 | pre-assembly | shell_B_seam_flush | 0.0 |  | pending | mm | <0.5 proud | visual + feeler gauge | shop | pending | Grind flush
VAL-006 | pre-assembly | shell_C_seam_flush | 0.0 |  | pending | mm | <0.5 proud | visual + feeler gauge | shop | pending | Grind flush
VAL-007 | pre-assembly | bearing_edge_sharpness | no_burr |  | pending | qualitative | zero sharp catches | finger-drag test | shop | pending | Re-file chamfer; check with magnifier
VAL-008 | pre-assembly | frame_flatness | 0.0 |  | pending | mm | <1.0 bow over 450mm | straightedge + feeler | shop | pending | Flatten by hand on surface plate; check flange welds
VAL-009 | tuning | drum_A_center_hz | 146.8 | 143.0 | pending | Hz | ±50 cents (~8 Hz at D3) | chromatic tuner | room temp 20C | pending | Tighten all rods ¼ turn; re-equalize; re-check
VAL-010 | tuning | drum_B_center_hz | 220.0 | 189.0 | pending | Hz | ±50 cents (~12 Hz at A3) | chromatic tuner | room temp 20C | pending | Tighten; Drum B needs highest tension — verify rods not binding
VAL-011 | tuning | drum_C_center_hz | 293.7 | 240.0 | pending | Hz | ±50 cents (~17 Hz at D4) | chromatic tuner | room temp 20C | pending | Tighten; smallest drum tunes fastest
VAL-012 | tuning | drum_A_rim_evenness | 146.8 |  | pending | Hz | ±10 cents between lug positions | tap each lug position + tuner | room temp | pending | Adjust individual rods; cross-tension pattern
VAL-013 | tuning | drum_B_rim_evenness | 220.0 |  | pending | Hz | ±10 cents between lug positions | tap each lug + tuner | room temp | pending | Adjust individual rods
VAL-014 | tuning | drum_C_rim_evenness | 293.7 |  | pending | Hz | ±10 cents between lug positions | tap each lug + tuner | room temp | pending | Adjust individual rods
VAL-015 | post-assembly | snare_A_disengage | no_rattle |  | pending | qualitative | zero rattle at full release | play and listen | room temp | pending | Check thumb-wheel clearance; snare wire may need retrimming
VAL-016 | post-assembly | snare_B_disengage | no_rattle |  | pending | qualitative | zero rattle at full release | play and listen | room temp | pending | See above
VAL-017 | post-assembly | snare_C_disengage | no_rattle |  | pending | qualitative | zero rattle at full release | play and listen | room temp | pending | See above
VAL-018 | post-assembly | cross_talk_A_to_B | below_threshold |  | pending | dB | adjacent drum resonance < −12 dB vs struck drum | SPL meter or phone mic | room temp | pending | Add rubber isolation pad between shell and frame cut-out
VAL-019 | post-assembly | cross_talk_B_to_C | below_threshold |  | pending | dB | adjacent drum < −12 dB | SPL meter or phone mic | room temp | pending | Isolation pads
VAL-020 | post-assembly | frame_rigidity | no_movement |  | pending | qualitative | zero drum shift under hard strike | visual | room temp | pending | Tighten M5 bolts; add lock washer if needed

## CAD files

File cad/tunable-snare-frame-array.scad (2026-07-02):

// Tunable Snare Frame Array parametric master — three shell envelopes +
// mounting frame envelope.
//
// Authority: pending_measurement. NOT fabrication authority until reviewed
// against a formed/welded prototype (see visual-output-register.csv V5-REG-027
// and cad/mcp-session-log.md).
//
// SCOPE: this master models (a) the three rolled-cylinder shell envelopes
// (Drum A/B/C, OD + depth only — wall-thickness offset, weld seam, bearing-
// edge chamfer, and lug-hole pattern are NOT modeled, see flat-pattern-
// checklist.md), and (b) the mounting-frame flat-blank envelope (web +
// folded flanges, per flat-pattern-checklist.md's resolved bend geometry).
//
// EXPLICITLY OUT OF SCOPE: the frame's per-drum cutout holes and exact drum
// center spacing. solidworks-plan.md itself flags this as unresolved — its
// own math check reads "127 + 50 + 101.5 + 40 + 76 = 394.5 mm for 3 radii +
// 2 gaps. Adjust spacing to 450 mm frame" (an open TODO), and the plan's
// stated cutout diameters (256/205/154 mm) do not fit inside the stated
// 80 mm web height as literal full circles. Rather than invent a resolution
// to that open contradiction, the three shells below are positioned at the
// plan's literal reference x-positions (60/185/300 mm) for layout reference
// ONLY — this is not cutout/fabrication authority. Fit-up must be resolved
// by a reviewed CAD session before L3.
//
// Dimension sources (do not edit values without updating the source record):
//   - drum_*_od_standard, drum_*_depth, shell_thickness_mm: parameters.csv
//   - frame web/flange/thickness: flat-pattern-checklist.md "Frame Flat Blank"
//     (450.0mm width, 131.5mm flat blank height = 20 + 5.74 + 80 + 5.74 + 20)
//   - drum reference x-positions (60/185/300mm): solidworks-plan.md
//     "Mounting Frame Modeling" step 4 (explicitly flagged unresolved there)
//
// Units: millimeters.

/* [Shell envelopes — parameters.csv, Remo Ambassador catalog ODs] */
drum_a_od_mm   = 254; // parameters.csv drum_a_od_standard (10in)
drum_a_depth_mm = 60; // parameters.csv drum_a_depth
drum_b_od_mm   = 203; // parameters.csv drum_b_od_standard (8in)
drum_b_depth_mm = 50; // parameters.csv drum_b_depth
drum_c_od_mm   = 152; // parameters.csv drum_c_od_standard (6in)
drum_c_depth_mm = 40; // parameters.csv drum_c_depth
shell_thickness_mm = 1.0; // parameters.csv shell_thickness_mm (documented,
                           // not modeled as a wall offset — see SCOPE above)

/* [Mounting frame — flat-pattern-checklist.md "Frame Flat Blank", resolved] */
frame_width_mm      = 450;  // flat-pattern-checklist.md
frame_web_height_mm = 80;   // flat-pattern-checklist.md (web only, formed part)
frame_flange_mm     = 20;   // flat-pattern-checklist.md (each end, formed 90deg)
frame_thickness_mm  = 1.5;  // parameters.csv frame_thickness_mm

/* [Reference layout only — solidworks-plan.md, NOT cutout authority] */
drum_a_x_mm = 60;
drum_b_x_mm = 185;
drum_c_x_mm = 300;

$fn = 96;

module drum_shell(od, depth, x) {
  translate([x, frame_thickness_mm, frame_web_height_mm / 2])
    rotate([-90, 0, 0])
      cylinder(h = depth, d = od);
}

module mounting_frame() {
  // Web: flat panel, width x web_height, thickness along Y.
  cube([frame_width_mm, frame_thickness_mm, frame_web_height_mm]);
  // Bottom flange, folded 90deg toward +Y (drum side).
  translate([0, 0, 0])
    cube([frame_width_mm, frame_flange_mm, frame_thickness_mm]);
  // Top flange, folded 90deg toward +Y (drum side).
  translate([0, 0, frame_web_height_mm - frame_thickness_mm])
    cube([frame_width_mm, frame_flange_mm, frame_thickness_mm]);
}

module snare_array_assembly() {
  mounting_frame();
  drum_shell(drum_a_od_mm, drum_a_depth_mm, drum_a_x_mm);
  drum_shell(drum_b_od_mm, drum_b_depth_mm, drum_b_x_mm);
  drum_shell(drum_c_od_mm, drum_c_depth_mm, drum_c_x_mm);
}

snare_array_assembly();

// Render-time check against flat-pattern-checklist.md flat blank height:
// 20 + 5.74 + 80 + 5.74 + 20 = 131.5mm (bend-allowance not modeled in the
// formed-part envelope above; echoed here for cross-reference only).
echo(str("flat_blank_height_check_mm=", 20 + 5.74 + 80 + 5.74 + 20));
echo("NOTE: frame cutouts + exact drum spacing are unresolved in source docs (see SCOPE) — not modeled.");

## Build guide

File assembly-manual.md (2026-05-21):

<!-- SPDX-License-Identifier: CC-BY-4.0 -->
# Assembly Manual — Tunable Snare Frame Array

## Tools for Assembly

- Drum key (standard 8-32 or M5 version matching lug hardware)
- Chromatic tuner (phone app or clip-on)
- Combination square
- M5 hex driver

---

## Part Check Before Assembly

- [ ] 3× welded steel shells (⌀254, ⌀203, ⌀152 mm)
- [ ] 1× plasma-cut mounting frame with flanges bent
- [ ] 3× Remo Ambassador heads (10″, 8″, 6″)
- [ ] 3× counter-hoops (matching each head size)
- [ ] 6+6+4 = 16× tension rods + washers (drum-standard 8-32 or M5)
- [ ] 6+6+4 = 16× drum lugs (bought, mounted to shell lug ears)
- [ ] 3× snare wire mechanisms with thumb-wheel (bought)
- [ ] 12× M5 bolts + nuts for shell-to-frame mounting
- [ ] 3× snare wire bundles (12, 10, 8 strand)

---

## Assembly Sequence

### Step 1 — Mount Shells to Frame (5 min)

1. Insert Shell A (254 mm, largest) into the leftmost frame cut-out from the drum-face side.
2. Pass M5 bolts through frame lug ear holes into shells. Finger-tight.
3. Verify shell sits flush with frame face; no rocking. Tighten M5 bolts to snug.
4. Repeat for Shell B (center), Shell C (right).
5. Check all three shells are parallel (level along top rims).

*[Photo placeholder: frame with 3 shells mounted, rear view showing bolt pattern]*

### Step 2 — Install Lugs on Shell Ears (10 min)

1. If lugs not pre-mounted: bolt each lug to its shell ear using M5 (or 8-32) screw. Lugs should spin freely and not wobble.
2. Inspect all 16 lug anchors — no cross-threading.

*[Photo placeholder: close-up of lug ear + lug on Shell A]*

### Step 3 — Seat Drum Heads (5 min)

1. Place Remo Ambassador 10″ on Shell A. Center it; the head rim should seat smoothly on the bearing edge.
2. Place counter-hoop over head.
3. Thread tension rods through counter-hoop into lugs — finger-tight only. Install all rods before tensioning.
4. Repeat for Shell B (8″) and Shell C (6″).

*[Photo placeholder: head seated on Shell C, counter-hoop in place, rods finger-tight]*

### Step 4 — Install Snare Mechanisms (5 min)

1. For each drum: loop snare wires across the batter head (bottom face of head). The thumb-wheel bracket should be positioned at 6 o'clock (bottom of drum face).
2. Mount bracket to nearest lug ear or dedicated snare bracket weld point.
3. Thread snare wire anchor to bracket; snug thumb-wheel to light contact tension.

*[Photo placeholder: snare wire across head, thumb-wheel at 6 o'clock position]*

### Step 5 — Tune to Target Pitches (20 min)

See `tuning-notes.md` for full procedure. Summary:

1. Cross-tension all rods ¼-turn increments until head rings when tapped.
2. Tap near each lug; equalize pitch around the rim.
3. Strike center; read chromatic tuner:
   - Shell C target: D4 ≈ 294 Hz
   - Shell B target: A3 ≈ 220 Hz
   - Shell A target: D3 ≈ 147 Hz
4. Once within ±50 cents: detune, re-tension 2× more to seat head.
5. Final tune: mark rod extension with paint pen.

*[Photo placeholder: tuner showing D4 on Shell C, rod markings visible]*

### Step 6 — Snare Adjustment and Final Check (5 min)

1. Disengage all snare mechanisms (fully loosen thumb-wheels).
2. Strike each drum; confirm clear tone, no rattle.
3. Re-engage snares halfway; confirm buzz activates on each drum.
4. Play all three drums in sequence: check no resonance transfer between drums.

---

## Maintenance Notes

- **Re-tuning**: temperature and humidity change head tension. Re-check pitch before each play session.
- **Head replacement**: standard Remo Ambassador heads; available at any drum shop.
- **Snare wire**: replace if worn or buzzing unevenly; standard snare wire bundles fit.
- **Frame**: no maintenance required; clean with dry cloth.

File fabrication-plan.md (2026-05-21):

<!-- SPDX-License-Identifier: CC-BY-4.0 -->
# Fabrication Plan — Tunable Snare Frame Array

## Maker Nexus Tools Required

| Tool | Use |
|---|-----|
| Plasma cutter (Hypertherm 45XP or similar) | Frame flat blank + lug ears |
| Slip-roll (e.g. Jet R-3 or Di-Acro 12") | Roll shell cylinders |
| TIG welder (Miller Dynasty or similar) | Butt-weld cylinder seams |
| Angle grinder + flap disc | Seam flush-grind + deburr |
| Drill press | Lug holes in shells |
| Brake press | Frame flange bends |
| Belt grinder / file | Bearing edge chamfer |
| Drum key, chromatic tuner | Head tensioning + pitch verification |

---

## Step-by-Step Sequence

### Stage 1 — Cut Blanks

1. Mark stock 1.0 mm CRS for three shell blanks; cut with plasma or shear:
   - Shell A: 798.0 mm × 60.0 mm
   - Shell B: 637.7 mm × 50.0 mm
   - Shell C: 477.5 mm × 40.0 mm
2. Mark stock 1.5 mm CRS for frame: 450.0 mm × 131.5 mm; plasma-cut three circular holes:
   - Drum A hole: ⌀256 mm at x=60, y=65.75 (center of 131.5 mm frame)
   - Drum B hole: ⌀205 mm at x=185, y=65.75
   - Drum C hole: ⌀154 mm at x=310, y=65.75
   - Also plasma: 12× M5 clearance holes (⌀5.5 mm) around each circle at ±20 mm from edge
3. Plasma 16× lug ear blanks from 1.5 mm CRS: 60 mm × 40 mm each. Mark fold line at 15 mm.
4. Deburr all plasma-cut edges with file/grinder.

### Stage 2 — Form Cylinders

5. Slip-roll Shell C (smallest) first as coupon. 3-roller setup; pass blank through at progressive settings until ⌀152 mm OD achieved. Measure OD with calipers or wrap tape measure.
   - Overshoot by 1–2 mm then spring back; iterate.
6. Check seam alignment: butt edges should meet flush within 0.5 mm gap.
7. TIG butt-weld seam: 1.0 mm CRS, 40A, DCEN, ER70S-6 filler. Tack 3 spots, then run seam bottom to top. Avoid warping — short passes, let cool.
8. Grind seam flush: flap disc until OD is smooth. Confirm OD within ±0.5 mm of nominal.
9. Repeat for Shell B, then Shell A (each progressively larger radius is easier to roll).

### Stage 3 — Bearing Edge + Lug Holes

10. File or belt-grind 45° × 1.0 mm chamfer on top rim OD of each shell. Run finger along edge — zero sharp burr acceptable. This is the head bearing edge.
11. Drill 4× (Shell C) or 6× (Shell A, B) M5 clearance holes (⌀5.5 mm) at 15 mm from top rim using drill press + V-block fixture to hold cylinder. Mark positions with transfer punch.
12. Deburr all holes inside and outside with countersink.

### Stage 4 — Form Frame

13. Brake press: bend top flange (20 mm) 90° inward at y = 25.74 mm from top edge of blank.
14. Brake press: bend bottom flange (20 mm) 90° inward at y = 25.74 mm from bottom edge.
15. Check flanges square with combination square. Both flanges fold toward drum-mounting side.
16. Fold 16× lug ear blanks: 90° bend at 15 mm mark (brake or vise + block). Base tab is 15 mm × 60 mm; ear body is 25 mm × 60 mm.

### Stage 5 — Weld Lug Ears to Shells

17. Position 4 ears (per Shell C) or 6 ears (per Shell A, B) on shell OD at lug hole positions. Align ear base tab with lug hole. Tack-weld.
18. Verify ear angle perpendicular to shell axis using square.
19. Complete weld all ears.

### Stage 6 — Assembly

20. Drop each shell into its frame cut-out. Lug ears pass through frame from drum side; M5 bolts secure from frame side.
21. Install counter-hoop and drum head: seat Remo Ambassador 6/8/10" onto shell rim; place counter-hoop; install tension rods through counter-hoop → lug → rod.
22. Finger-tighten all rods. Equalize with cross-tension pattern (see `tuning-notes.md`).
23. Install snare mechanism: snare wires lay across batter head bottom edge; thumb-wheel tensioner mounts to lug ear or dedicated bracket.

### Stage 7 — Tune and Validate

24. Tension drums to target frequencies (see `tuning-notes.md` and `validation.csv`).
25. Verify all acceptance targets in `validation.csv`.
26. Mark lug rod extension with paint pen at target tension for repeatability.

---

## Material Stock Required

- 1.0 mm CRS sheet: 1× sheet 300 × 900 mm covers Shell A + B + C blanks
- 1.5 mm CRS sheet: 1× sheet 500 × 500 mm covers frame + lug ear stock
- ER70S-6 TIG rod, flap disc, M5 hardware

---

## Inspection Gates

| Gate | Criteria | Point |
|---|---|---|
| Shell OD | ±0.5 mm of nominal after weld + grind | After Stage 2 |
| Seam flush | < 0.5 mm proud | After Stage 2 |
| Bearing edge | No sharp burrs; smooth 45° chamfer | After Stage 3 |
| Lug holes | ±0.5 mm position; no raised burrs inside shell | After Stage 3 |
| Frame flatness | < 1 mm bow over 450 mm span | After Stage 4 |
| Head seating | Head seats with no visible gap around rim | After Stage 6 |
| Pitch | Center fundamental within ±50 cents of target | After Stage 7 |

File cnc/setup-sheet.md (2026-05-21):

<!-- SPDX-License-Identifier: CC-BY-4.0 -->
# CNC / Plasma Setup Sheet — Tunable Snare Frame Array

## Plasma Cutter Setup (Hypertherm 45XP or similar)

| Setting | Value |
|---|---|
| Material | Cold-rolled steel (CRS) |
| 1.0 mm stock amperage | 25–30 A |
| 1.5 mm stock amperage | 35–40 A |
| Cut speed 1.0 mm | 60–70 IPM |
| Cut speed 1.5 mm | 45–55 IPM |
| Kerf allowance | 1.5 mm (add 0.75 mm each side of cut line) |
| Air pressure | 65–70 PSI |
| Tip | Fine-cut consumable set |

**DXF Setup**: Load `drawings/frame_flat_blank.dxf` into Hypertherm CAM or SheetCam. Assign cut layer to `CUT`; verify all circle cut-outs and slot holes are on cut layer. Run toolpath simulation before cutting.

## Slip-Roll Setup (Jet R-3 or Di-Acro 12")

| Shell | Target OD | Starting Roll Gap |
|---|---|---|
| Shell C | 152 mm | ~180 mm gap setting |
| Shell B | 203 mm | ~230 mm gap setting |
| Shell A | 254 mm | ~280 mm gap setting |

**Process**: Feed blank narrow edge first (60/50/40 mm edge = shell height). Roll at mid-pressure; re-check OD with calipers after each pass. Adjust bottom roll pinch to tighten or loosen radius. Final pass should overshoot ~2 mm; butt edges together and tack-weld to maintain OD.

## Brake Press Setup

| Bend | Part | Die | Punch | Stroke |
|---|---|-----|---|---|
| FRM-B01 | Mounting frame top flange | V-die 8mm | Standard | 90° |
| FRM-B02 | Mounting frame bottom flange | V-die 8mm | Standard | 90° |
| LUG-EAR | Lug ear base tab | V-die 8mm | Standard | 90° |

**Note**: Brake bends in 1.5 mm CRS. Die opening should be 6–8× material thickness = 9–12 mm V-die. Use 8 mm V-die if available.

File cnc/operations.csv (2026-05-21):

# SPDX-License-Identifier: CERN-OHL-W-2.0
op_id | part | machine | operation | tool | speed_ipm | kerf_mm | passes | notes
OP-01 | shell_A_blank | plasma cutter | profile cut 798x60mm rectangle | Hypertherm 45XP | 60 | 1.5 | 1 | Shear preferred if available; plasma for speed
OP-02 | shell_B_blank | plasma cutter | profile cut 638x50mm rectangle | Hypertherm 45XP | 60 | 1.5 | 1 | Can nest B + C on same stock panel as A
OP-03 | shell_C_blank | plasma cutter | profile cut 478x40mm rectangle | Hypertherm 45XP | 65 | 1.5 | 1 | Smallest blank; nest at end of 300x900 sheet
OP-04 | mounting_frame | plasma cutter | profile cut 450x131.5mm + 3 circles + holes | Hypertherm 45XP | 50 | 1.5 | 1 | CAD: use DXF from drawings/frame_flat_blank.dxf
OP-05 | lug_ear | plasma cutter | profile cut 60x40mm blanks x16 | Hypertherm 45XP | 65 | 1.5 | 1 | Nest all 16 on 16-gauge scrap
OP-06 | shell_A_blank | slip-roll | roll to 254mm OD cylinder | 3-roller slip-roll | manual | n/a | 2-3 | Start at 300mm setting; iterate to 254mm OD; measure each pass
OP-07 | shell_B_blank | slip-roll | roll to 203mm OD cylinder | 3-roller slip-roll | manual | n/a | 2-3 | Start at 240mm; iterate
OP-08 | shell_C_blank | slip-roll | roll to 152mm OD cylinder | 3-roller slip-roll | manual | n/a | 2-3 | Start at 180mm; iterate; smallest cylinder — watch for creasing
OP-09 | mounting_frame | brake press | bend top + bottom flanges 90deg | brake press | manual | n/a | 2 | See bend-table.csv FRM-B01/FRM-B02

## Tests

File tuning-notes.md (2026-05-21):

<!-- SPDX-License-Identifier: CC-BY-4.0 -->
# Tuning Notes — Tunable Snare Frame Array

## Pitch Set Rationale

Three pitches: D3 (146.8 Hz), A3 (220.0 Hz), D4 (293.7 Hz).

- D3 → A3: perfect 5th (frequency ratio 3:2 = 1.5×)
- A3 → D4: perfect 4th (frequency ratio 4:3 ≈ 1.333×)
- D3 → D4: octave (frequency ratio 2:1)

This yields a D–A–D open-tuned trio. Players can re-tune to any 3-note set (blues minor 3rd + 5th, chromatic cluster, sus4) by adjusting individual head tensions.

## Membrane Physics

Circular membrane fundamental: `f₀₁ = (2.4048 / (2πr)) · √(T/σ)`

Solving for required tension to hit target pitch:

```
T_required = σ · (f₀₁ · 2πr / 2.4048)²
```

At σ = 0.18 kg/m²:

| Drum | r (m) | f target | T required (N/m) |
|---|---|---|---|
| A (10″) | 0.127 | 146.8 Hz | 1160 N/m |
| B (8″) | 0.1015 | 220.0 Hz | 2540 N/m |
| C (6″) | 0.076 | 293.7 Hz | 2250 N/m |

Drum B (8″, A3) requires the highest tension (~2540 N/m). This approaches but does not exceed the Remo Ambassador burst spec estimate (~3000 N/m). Verify with first prototype.

## Tuning Mechanism

Standard drum lug hardware — 6-lug on 10″ and 8″ drums, 4-lug on 6″ drum. Tension rods (M5 or 8-32) engage counter-hoop anchored lugs welded to shell exterior.

Procedure:
1. Finger-tighten all rods to seat head.
2. Cross-tension pattern (opposite lugs): ¼-turn increments.
3. Tap near each lug and compare pitch — equalize before checking center.
4. Strike center; read on chromatic tuner. Target pitch ± 50 cents is Stage 1 acceptance.
5. Detune → retighten 3× for head seating before final measurement.

## Harmonic Series

Circular membrane modes above the fundamental:
- Mode (1,1): 1.594 × f₀₁
- Mode (2,1): 2.136 × f₀₁
- Mode (0,2): 2.295 × f₀₁

These are inharmonic (not integer multiples). The drum tone character — that slightly untuned metallic quality — comes from these inharmonic partials. The snare buzz masks the higher partials and adds broadband noise, traditional to snare drums.

## Snare Tuning

Snare wires rest against the batter-side head (or bottom resonant head if double-headed, though this design is single-head). A thumb-wheel tensioner controls snare contact pressure:
- Full release: clean membrane tone, jazz-brush character
- Light contact: slight buzz, add-on shimmer
- Full contact: classic snare rattle

Snare wire pitch is not adjustable separately; it tracks the head fundamental.

## Alternate Tuning Sets

| Set name | Drum A | Drum B | Drum C |
|---|---|---|---|
| D–A–D (default) | D3 | A3 | D4 |
| Blues cluster | D3 | F3 | A3 |
| Chromatic leading | D3 | Eb3 | E3 |
| Open 5th power | C3 | G3 | C4 |

Head σ uncertainty (±20%) shifts all targets; tune by ear against tuner reference.

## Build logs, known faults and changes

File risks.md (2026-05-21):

<!-- SPDX-License-Identifier: CC-BY-4.0 -->
# Risks — Tunable Snare Frame Array

## Safety Risks

| Risk | Severity | Probability | Mitigation |
|---|---|---|---|
| Sharp bearing edge cuts drum head or hand | High | Medium | File/grind 45° chamfer carefully; inspect with finger drag before assembly |
| Weld spatter burns during TIG | Medium | High | Full PPE — gloves, auto-darkening helmet, long sleeves |
| Plasma-cut edge burrs | Medium | High | Deburr all edges before handling; bench-grinder or file |
| Cylinder roll-out injury (blank feeds back) | High | Low | Feed blank slowly; keep hands clear of pinch zone |
| TIG arc flash to bystanders | High | Low | Post "welding in progress" warning; clear 3m radius |

## Ergonomic Risks

| Risk | Severity | Probability | Mitigation |
|---|---|---|---|
| Frame too wide for single player (550mm) | Medium | Low | Confirmed playable for players with 550mm+ arm span; ok for tabletop |
| Drum heights uneven when frame is angled | Low | Medium | Design for flat tabletop or stand-mount; add leveling feet if needed |
| Head too tight to tune without drum key | Low | Medium | Provide drum key in BOM; wing-nut tension rods as upgrade option |

## Manufacturability Risks

| Risk | Severity | Probability | Mitigation |
|---|---|---|---|
| Shell OD tolerance vs head counter-hoop fit | High | Medium | Standard drum heads spec ±0.5mm; roll shells to within ±0.5mm; Remo Ambassador is forgiving |
| Cylinder seam misalignment during roll | Medium | High | Tack-weld quickly after rolling; check alignment before full weld |
| Shell C (152mm) too small to roll cleanly | Medium | Medium | Run roll coupon first; watch for creasing near 6in OD; may need to anneal if using harder CRS |
| Frame cut-out diameter wrong (head won't drop in) | High | Low | Add 2mm clearance per side (cut-out = head OD + 4mm); verify on coupon before final plasma |
| Lug ear position mismatch after weld | Medium | Medium | Jig ears before tacking; use a simple 3D-printed or bent-wire locating jig |

## Acoustic Failure Modes

| Risk | Severity | Probability | Mitigation |
|---|---|---|---|
| Drum B (8in, A3) exceeds Remo head burst tension | High | Low | wolfram model predicts T_required = 2540 N/m vs ~3000 N/m burst; 15% margin; verify with first head |
| Real head σ differs from nominal 0.18 kg/m² | Medium | High | Tune by ear to target frequency; wolfram T values are starting points only |
| Snare wire buzz at low tensions | Low | High | Expected and desirable; adjust with thumb-wheel |
| Frame resonance couples between drums | Medium | Low | Add rubber grommets at shell-to-frame interface; test cross-talk with VAL-018/019 |
| Heads detune with temperature/humidity | Low | High | Normal drum behavior; player re-tunes before each session |

## Notes on Prototype Approach

This is an L0 blueprint — no prototype exists. All targets are model-derived. The highest-risk unknown is shell roll accuracy at 152mm OD (Shell C), because small-radius rolls on 1.0mm CRS are at the limit of typical Maker Nexus slip-roll capacity. Run the Shell C coupon first.

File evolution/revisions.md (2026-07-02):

# Revision Register — tunable-snare-frame-array

| Rev | Date | Parent | Delta | Downstream artifacts invalidated |
| --- | --- | --- | --- | --- |
| A | 2026-07-01 | — | Stage 0 intake of current masters (cad/tunable-snare-frame-array.scad + parameters.csv). | none (no alpha/beta/production artifacts exist yet) |

Stage 0 only. Gate A has not been run; no Alpha compiles, vendor quotes, or production lock exist for this product.

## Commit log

2026-05-21 feat: parametric design.md and parameters.csv (#1)
    [parameters.csv]
2026-05-21 feat: solidworks plan + flat-pattern checklist (#2)
    [bend-table.csv, cut-list.csv]
2026-05-21 feat: fabrication plan + assembly manual (#3)
    [bom.csv, hardware.csv, operations.csv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]
2026-05-21 feat: wolfram acoustic model + validation predictions (#4)
    [validation.csv]
2026-05-30 feat: V5 surface — visual-output-register, mcp-session-log, L2 status (#6)
    Refs instrument-maker#184
    [visual-output-register.csv]
2026-05-30 chore(tunable-snare-frame-array): add .gitignore (Refs instrument-maker#195) (#7)
2026-05-31 wolfram-rename(tunable-snare-frame-array): unique {slug}-starter.wl + dedupe + ref fixes (cloud-sync naming) (#8)
    [visual-output-register.csv]
2026-05-31 docs(tunable-snare-frame-array): add image-gen prompt (#9)
2026-05-31 Add image-gen concept prompt; wire explorer images
2026-06-23 feat(v5): explorer V5 upgrade + build-packet gaps — tunable-snare-frame-array (#10)
    * feat(v5): upgrade explorer to V5 format + fill build-packet gaps
    - Replace explorer.html with V5 parchment card format: readiness chip,
    authority-split chip, family chip, per-artifact authority badges
    (fabrication / derived_preview / reference_only / source_only)
    - Add data/deliverables-export.json machine-readable manifest
    - Add any missing build-packet stubs (drawing-brief.md, assembly-manual.md,
    supplier-rfq.md, visual-bom-brief.md, photo-shotlist.md, sourcing.csv,
    cut-list.csv, cnc/setup-sheet.md) as TBD-ready placeholders
    Refs instrument-maker v4.5 · tonykoop/tunable-snare-frame-array
    Co-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
2026-07-02 V5 packet refresh: status line, provenance, parametric OpenSCAD master, evolution intake
    - README.md: add cad/.scad + evolution/ quick-start rows (status line was
    already correctly formatted)
    - cad/tunable-snare-frame-array.scad: new parametric master — three rolled-
    cylinder shell envelopes (Drum A/B/C) + mounting-frame flat/flange
    envelope. Frame cutout holes and exact drum spacing intentionally NOT
    modeled: solidworks-plan.md's own math check flags that spacing as
    unresolved ("Adjust spacing to 450 mm frame"), and its stated cutout
    diameters don't fit the stated 80mm web height as literal circles — rather
    than invent a resolution, the master uses the plan's literal refer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
    [tunable-snare-frame-array.scad, visual-output-register.csv]
